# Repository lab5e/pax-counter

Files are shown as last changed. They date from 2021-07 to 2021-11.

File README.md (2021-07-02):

# PAX Counter

This device scans for visible bluetooth and wifi devices and then transmits the device count over NBIoT to a backend server.

IP67 version

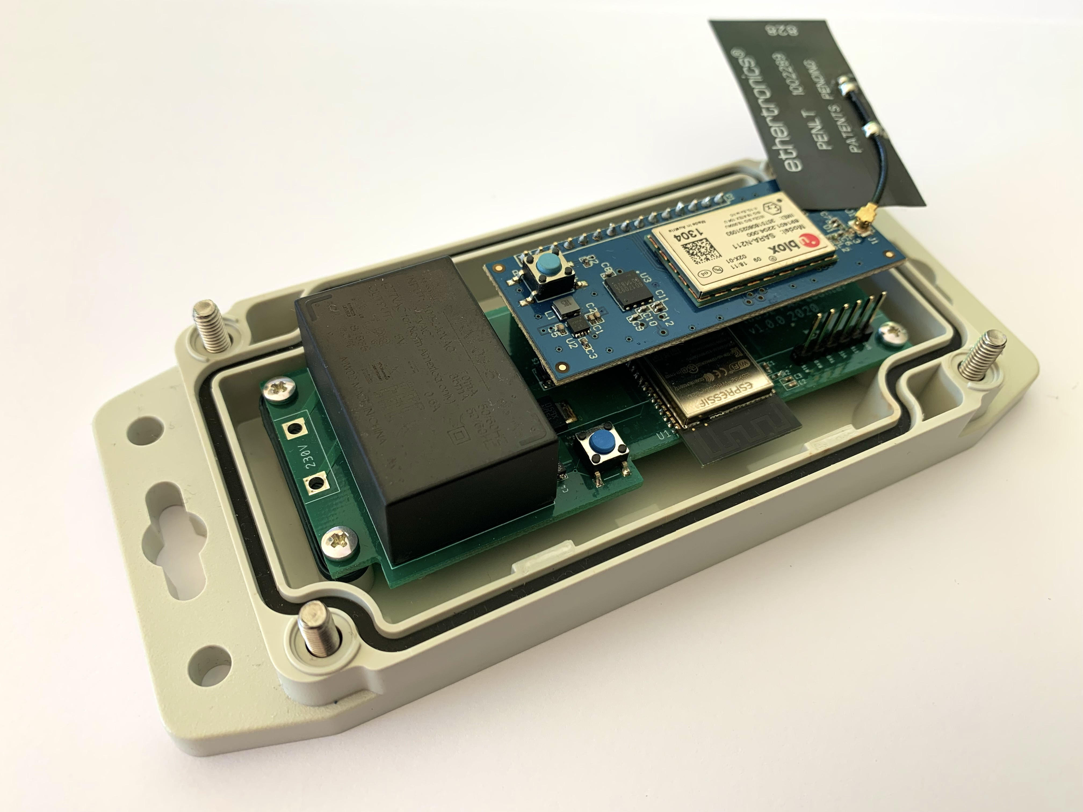
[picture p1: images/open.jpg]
open


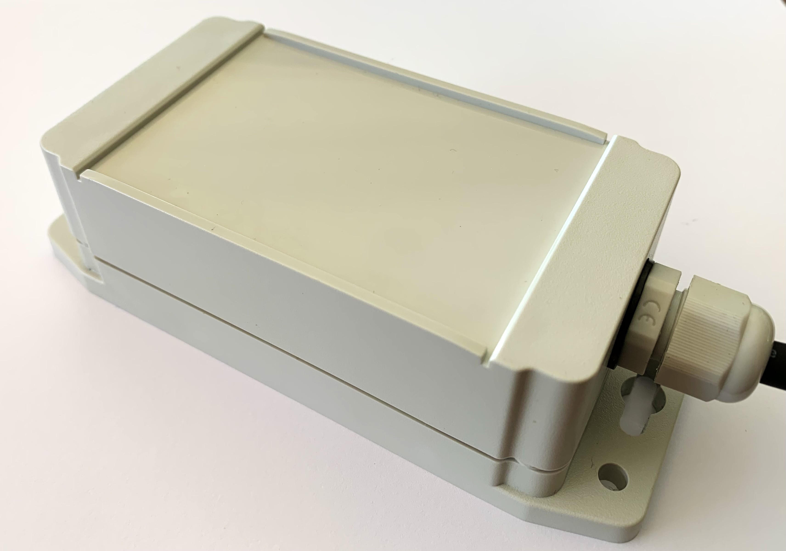
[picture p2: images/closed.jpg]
closed


Enclosure: [1555CF22GY](https://www.digikey.no/products/no?keywords=1555cf22) from Hammond Manufacturing

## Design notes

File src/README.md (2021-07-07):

# Note

Newer versions of BLEAdvertisedDevice.cpp, BLEAdvertisedDevice.h, BLEScan.h, BLEScan.cpp etc may be found here: [https://github.com/nkolban/esp32-snippets/tree/master/cpp_utils](https://github.com/nkolban/esp32-snippets/tree/master/cpp_utils).

(Consider switching to these if stuff get's weird)

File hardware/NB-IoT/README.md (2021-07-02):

# IP67 PAX Counter

## BoM

* C1	10uF 0402
* C2	10uF 0402
* C3	0.1uF CAP_0402
* C4	10uF Tantalum 1206
* C5	100uF Tantalum 1206
* J1	FTDI_CONNECTOR
* R1	10k	0402
* R2	10k		0402
* S1	SWITCH PTS645
* U1	ESP-WROOM-32D
* U2	15 pin female header (2.54)
* U3	IRM-03-5
* U4    LM1117	SOT-223
* [1555CF22GY](https://www.digikey.no/products/no?keywords=1555cf22) enclosure

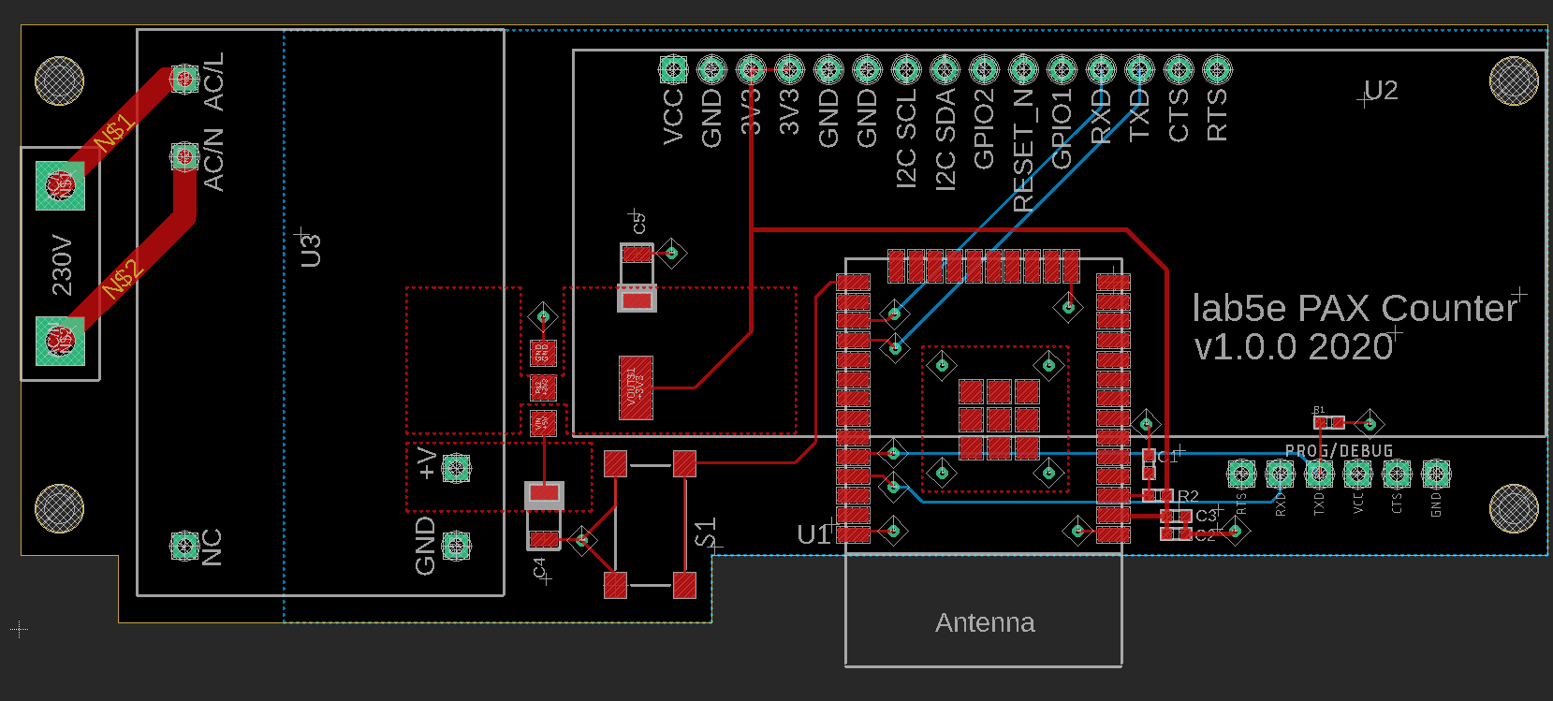
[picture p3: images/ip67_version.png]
Eagle board


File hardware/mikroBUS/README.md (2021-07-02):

# mikroBUS PAX Counter

(Work in progress)

## BoM
* ESP-WROOM-32D
* PTS645 SMT switch
* 2 x 0402 10k resistor
* 1 x 6 pin 2.54mm pin header
* 2 x 8 pin 2.54mm pin header

[mikroBUS specification](https://download.mikroe.com/documents/standards/mikrobus/mikrobus-standard-specification-v200.pdf)

Eagle board

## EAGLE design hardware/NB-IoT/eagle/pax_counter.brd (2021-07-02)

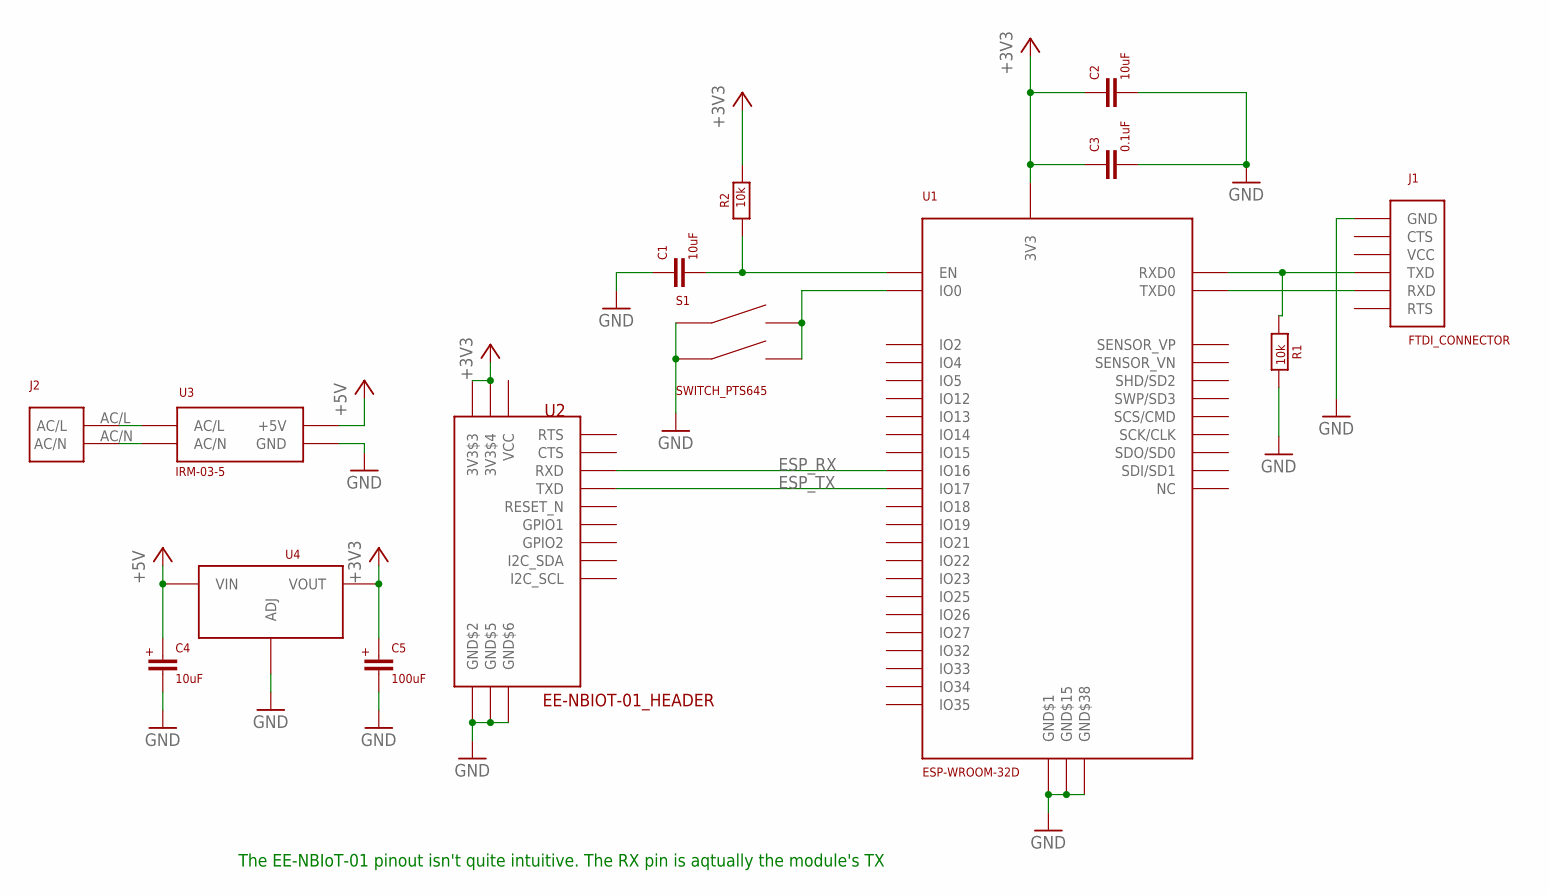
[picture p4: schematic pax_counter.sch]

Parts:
C1, C2: 10uF; CAP_0402
C3: 0.1uF; CAP_0402
C4: 10uF; TANTALUM_CAP_1206
C5: 100uF; TANTALUM_CAP_1206
J1: FTDI_CONNECTOR
J2: 240VAC_SOLDER_CONNECTOR
R1, R2: 10k; RES_0402
S1: SWITCH_PTS645; SWITCH_PTS645_EE_NBIOT_01
U1: ESP-WROOM-32D; ESP_WROOM_32D
U2: EE-NBIOT-01_HEADER
U3: IRM-03-5
U4: LM1117; SOT-223

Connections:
+3V3: C2.P$1 (1), C3.P$1 (1), C5.V+ (+), R2.P$2, U1.2 (3V3), U2.3V3$3, U2.3V3$4, U4.P$2 (VOUT), U4.VOUT$1 (VOUT)
+5V: C4.V+ (+), U3.+5V, U4.VIN
ESP_RX: U1.27 (IO16), U2.RXD
ESP_TX: U1.28 (IO17), U2.TXD
GND: C1.P$1 (1), C2.P$2 (2), C3.P$2 (2), C4.GND (-), C5.GND (-), J1.GND, R1.P$2, S1.A1, S1.A2, U1.1 (GND$1), U1.15 (GND$15), U1.38 (GND$38), U1.GND$39 (GND$38), U1.GND$40 (GND$38), U1.GND$41 (GND$38), U1.GND$42 (GND$38), U1.GND$43 (GND$38), U1.GND$44 (GND$38), U1.GND$45 (GND$38), U1.GND$46 (GND$38), U1.GND$47 (GND$38), U2.GND$2, U2.GND$5, U2.GND$6, U3.GND, U4.GND (ADJ)
unnamed: J2.AC/L, U3.AC/L
unnamed: J2.AC/N, U3.AC/N
unnamed: C1.P$2 (2), R2.P$1, U1.3 (EN)
unnamed: J1.TXD, R1.P$1, U1.34 (RXD0)
unnamed: J1.RXD, U1.35 (TXD0)
unnamed: S1.B1, S1.B2, U1.25 (IO0)

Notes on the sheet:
The EE-NBIoT-01 pinout isn't quite intuitive. The RX pin is aqtually the module's TX

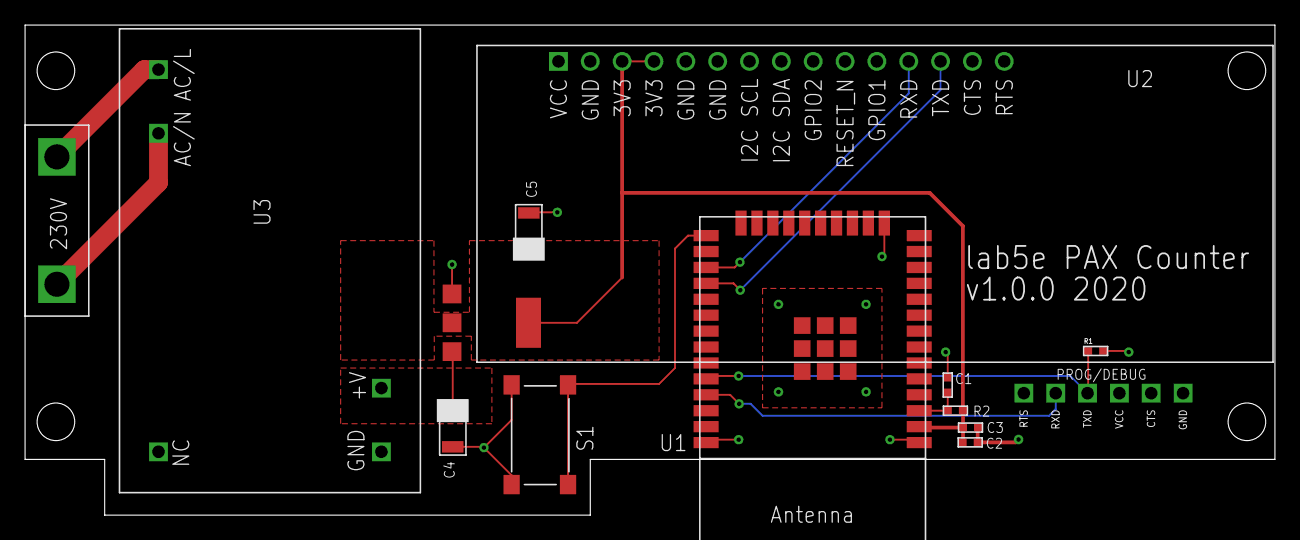
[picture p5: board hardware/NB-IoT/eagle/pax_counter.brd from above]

Board: 2 copper layers, 99.7 x 39.1 mm, 14 parts (0 on the bottom side), 11 nets.

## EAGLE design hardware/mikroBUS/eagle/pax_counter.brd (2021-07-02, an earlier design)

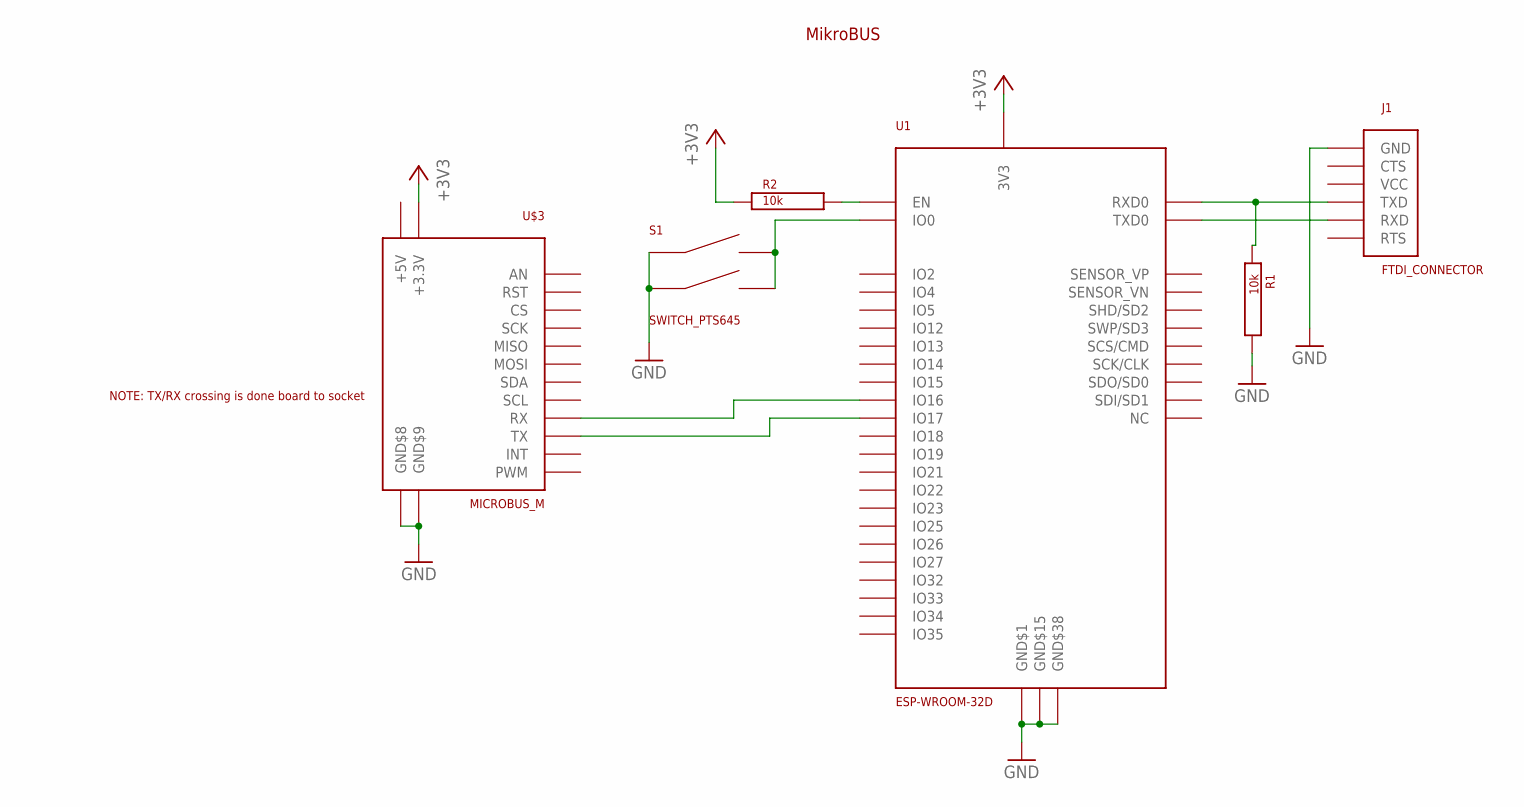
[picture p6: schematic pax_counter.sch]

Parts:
J1: FTDI_CONNECTOR
R1, R2: 10k; RES_0402
S1: SWITCH_PTS645; SWITCH_PTS645_EE_NBIOT_01
U1: ESP-WROOM-32D; ESP_WROOM_32D
U$1: MIKROBUS_LOGO
U$3: MICROBUS_M; MIKROBUS_M

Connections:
+3V3: R2.P$1, U1.2 (3V3), U$3.+3.3V
GND: J1.GND, R1.P$2, S1.A1, S1.A2, U1.1 (GND$1), U1.15 (GND$15), U1.38 (GND$38), U1.GND$39 (GND$38), U1.GND$40 (GND$38), U1.GND$41 (GND$38), U1.GND$42 (GND$38), U1.GND$43 (GND$38), U1.GND$44 (GND$38), U1.GND$45 (GND$38), U1.GND$46 (GND$38), U1.GND$47 (GND$38), U$3.GND$8, U$3.GND$9
unnamed: U1.27 (IO16), U$3.RX
unnamed: U1.28 (IO17), U$3.TX
unnamed: R2.P$2, U1.3 (EN)
unnamed: J1.TXD, R1.P$1, U1.34 (RXD0)
unnamed: J1.RXD, U1.35 (TXD0)
unnamed: S1.B1, S1.B2, U1.25 (IO0)

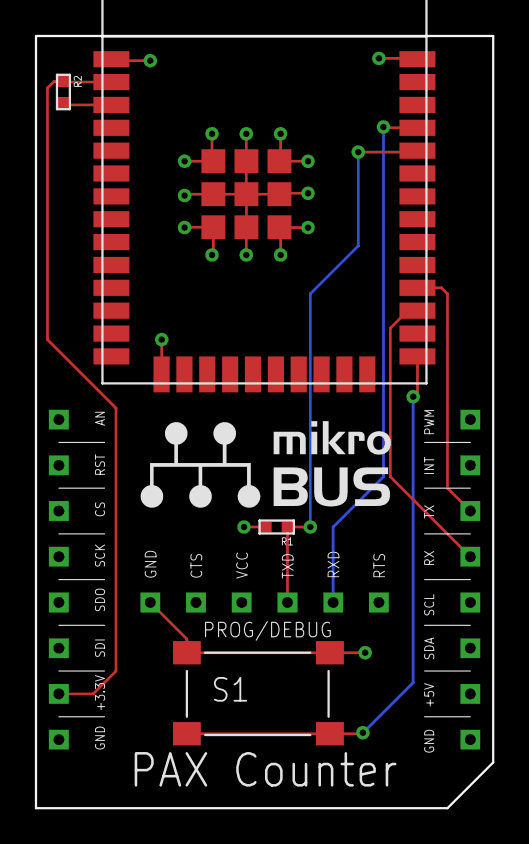
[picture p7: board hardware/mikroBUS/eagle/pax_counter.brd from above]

Board: 2 copper layers, 25.4 x 42.9 mm, 7 parts (0 on the bottom side), 8 nets.

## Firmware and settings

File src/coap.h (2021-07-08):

#ifndef _COAP_H_
#define _COAP_H_

#include <stdint.h>
#include <stddef.h>

// Default COAP parameters
#define DEFAULT_FOTA_COAP_REPORT_PATH   "u"
#define DEFAULT_FOTA_COAP_UPDATE_PATH   "fw"
#define DEFAULT_FOTA_COAP_PORT 5683


#define EINVAL   22

#define COAP_HEADER_VERSION(data)  ( (0xC0 & data[0])>>6    )
#define COAP_HEADER_TYPE(data)     ( (0x30 & data[0])>>4    )
#define COAP_HEADER_TKL(data)      ( (0x0F & data[0])>>0    )
#define COAP_HEADER_CLASS(data)    ( ((data[1]>>5)&0x07)    )
#define COAP_HEADER_CODE(data)     ( ((data[1]>>0)&0x1F)    )
#define COAP_HEADER_MID(data)      ( (data[2]<<8)|(data[3]) )

typedef struct
{
	char host[25];
	uint32_t port;
	char path[25];
	bool scheduled_update;
} simple_fota_response_t;

enum coap_method {
	COAP_METHOD_GET = 1,
	COAP_METHOD_POST = 2,
	COAP_METHOD_PUT = 3,
	COAP_METHOD_DELETE = 4,
};

#define COAP_REQUEST_MASK 0x07

struct coap_option {
	uint16_t delta;
#if defined(CONFIG_COAP_EXTENDED_OPTIONS_LEN)
	uint16_t len;
	uint8_t value[CONFIG_COAP_EXTENDED_OPTIONS_LEN_VALUE];
#else
	uint8_t len;
	uint8_t value[12];
#endif
};

enum coap_msgtype {
	/**
	 * Confirmable message.
	 *
	 * The packet is a request or response the destination end-point must
	 * acknowledge.
	 */
	COAP_TYPE_CON = 0,
	/**
	 * Non-confirmable message.
	 *
	 * The packet is a request or response that doesn't
	 * require acknowledgements.
	 */
	COAP_TYPE_NON_CON = 1,
	/**
	 * Acknowledge.
	 *
	 * Response to a confirmable message.
	 */
	COAP_TYPE_ACK = 2,
	/**
	 * Reset.
	 *
	 * Rejecting a packet for any reason is done by sending a message
	 * of this type.
	 */
	COAP_TYPE_RESET = 3
};

/**
 * @brief Set of CoAP packet options we are aware of.
 *
 * Users may add options other than these to their packets, provided
 * they know how to format them correctly. The only restriction is
 * that all options must be added to a packet in numeric order.
 *
 * Refer to RFC 7252, section 12.2 for more information.
 */
enum coap_option_num {
	COAP_OPTION_IF_MATCH = 1,
	COAP_OPTION_URI_HOST = 3,
	COAP_OPTION_ETAG = 4,
	COAP_OPTION_IF_NONE_MATCH = 5,
	COAP_OPTION_OBSERVE = 6,
	COAP_OPTION_URI_PORT = 7,
	COAP_OPTION_LOCATION_PATH = 8,
	COAP_OPTION_URI_PATH = 11,
	COAP_OPTION_CONTENT_FORMAT = 12,
	COAP_OPTION_MAX_AGE = 14,
	COAP_OPTION_URI_QUERY = 15,
	COAP_OPTION_ACCEPT = 17,
	COAP_OPTION_LOCATION_QUERY = 20,
	COAP_OPTION_BLOCK2 = 23,
	COAP_OPTION_BLOCK1 = 27,
	COAP_OPTION_SIZE2 = 28,
	COAP_OPTION_PROXY_URI = 35,
	COAP_OPTION_PROXY_SCHEME = 39,
	COAP_OPTION_SIZE1 = 60,
};

struct coap_packet 
{
	uint8_t *data;      // User allocated buffer 
	uint16_t offset;    // CoAP lib maintains offset while adding data 
	uint16_t max_len;   // Max CoAP packet data length 
	uint8_t hdr_len;    // CoAP header length 
	uint16_t opt_len;   // Total options length (delta + len + value) 
	uint16_t delta;     // Used for delta calculation in CoAP packet 
};

enum coap_block_size {
	COAP_BLOCK_16,
	COAP_BLOCK_32,
	COAP_BLOCK_64,
	COAP_BLOCK_128,
	COAP_BLOCK_256,
	COAP_BLOCK_512,
	COAP_BLOCK_1024,
};

// Represents the current state of a block-wise transaction.
struct coap_block_context {
	size_t total_size;
	size_t current;
	enum coap_block_size block_size;
};

#define coap_make_response_code(class, det) ((class << 5) | (det))


//  Set of response codes available for a response packet.
// 
//  To be used when creating a response.
// 
enum coap_response_code {
	COAP_RESPONSE_CODE_OK = coap_make_response_code(2, 0),
	COAP_RESPONSE_CODE_CREATED = coap_make_response_code(2, 1),
	COAP_RESPONSE_CODE_DELETED = coap_make_response_code(2, 2),
	COAP_RESPONSE_CODE_VALID = coap_make_response_code(2, 3),
	COAP_RESPONSE_CODE_CHANGED = coap_make_response_code(2, 4),
	COAP_RESPONSE_CODE_CONTENT = coap_make_response_code(2, 5),
	COAP_RESPONSE_CODE_CONTINUE = coap_make_response_code(2, 31),
	COAP_RESPONSE_CODE_BAD_REQUEST = coap_make_response_code(4, 0),
	COAP_RESPONSE_CODE_UNAUTHORIZED = coap_make_response_code(4, 1),
	COAP_RESPONSE_CODE_BAD_OPTION = coap_make_response_code(4, 2),
	COAP_RESPONSE_CODE_FORBIDDEN = coap_make_response_code(4, 3),
	COAP_RESPONSE_CODE_NOT_FOUND = coap_make_response_code(4, 4),
	COAP_RESPONSE_CODE_NOT_ALLOWED = coap_make_response_code(4, 5),
	COAP_RESPONSE_CODE_NOT_ACCEPTABLE = coap_make_response_code(4, 6),
	COAP_RESPONSE_CODE_INCOMPLETE = coap_make_response_code(4, 8),
	COAP_RESPONSE_CODE_PRECONDITION_FAILED = coap_make_response_code(4, 12),
	COAP_RESPONSE_CODE_REQUEST_TOO_LARGE = coap_make_response_code(4, 13),
	COAP_RESPONSE_CODE_UNSUPPORTED_CONTENT_FORMAT =
						coap_make_response_code(4, 15),
	COAP_RESPONSE_CODE_INTERNAL_ERROR = coap_make_response_code(5, 0),
	COAP_RESPONSE_CODE_NOT_IMPLEMENTED = coap_make_response_code(5, 1),
	COAP_RESPONSE_CODE_BAD_GATEWAY = coap_make_response_code(5, 2),
	COAP_RESPONSE_CODE_SERVICE_UNAVAILABLE = coap_make_response_code(5, 3),
	COAP_RESPONSE_CODE_GATEWAY_TIMEOUT = coap_make_response_code(5, 4),
	COAP_RESPONSE_CODE_PROXYING_NOT_SUPPORTED =
						coap_make_response_code(5, 5)
};

#define COAP_CODE_EMPTY (0)
#define COAP_TOKEN_MAX_LEN 8UL

#define ceiling_fraction(numerator, divider) \
	(((numerator) + ((divider) - 1)) / (divider))

#define ARRAY_SIZE(array) (sizeof(array) / sizeof((array)[0]))

int sys_csrand_get	(void * dst, size_t len);

int coap_packet_init(struct coap_packet *cpkt, uint8_t *data, uint16_t max_len,
		     uint8_t ver, uint8_t type, uint8_t token_len,
		     const uint8_t *token, uint8_t code, uint16_t id);

int fota_report_version(simple_fota_response_t *resp);



void test_coap();

#endif // _COAP_H_

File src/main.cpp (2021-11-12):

#include <Arduino.h>

#include "TelenorNBIot.h"
#include "wifi_scan.h"
#include "ble_scan.h"
#include "mac_pool.h"
#include <esp_task_wdt.h> 



MACAddressPool pool(300000); // Age limit: 5 minutes

#define TRANSMIT_DELAY_MS 1000 * 60 * 2 // Transmit every 2 minutes
#define BOOT_DELAY_MS 1000 * 60 * 120  // Reboot every second hour

extern "C" 
{
  uint8_t temprature_sens_read();
}

// void(* resetFunc) (void) = 0;

#define WDT_TIMEOUT 3 * 60 // 3 minute watchdog

void setup() 
{
  Serial.begin(115200);
  delay(1000);
  Serial.printf("Enabling watchdog timer. Timeout: %d\n", WDT_TIMEOUT);
  esp_task_wdt_init(WDT_TIMEOUT, true); //enable panic so ESP32 restarts
  esp_task_wdt_add(NULL); //add current thread to WDT watch

  wifi_scanner_setup();
  ble_scanner_setup();
  nbiot_setup();
 }

uint32_t seconds_uptime = 0;
uint sequence_number = 0;
void loop() 
{
  unsigned long boot_time_start, boot_time_end, transmit_time_start, transmit_time_end;

  boot_time_start = millis();
  while (true)
  {
    transmit_time_start = millis();
    while (true)
    {
      wifi_scan();
      ble_scanner_setup();
      ble_scan();
      ble_scanner_teardown();
      nbiot_status();
      esp_task_wdt_reset();
      pool.Log();
      transmit_time_end  = millis();
      boot_time_end = millis();
      float core_temperature = (temprature_sens_read() - 32) / 1.8;
      Serial.print("Core temperature:");
      Serial.println(core_temperature);
      if (transmit_time_end-transmit_time_start > TRANSMIT_DELAY_MS)
      {
        Serial.println("Transmitting...");
        sequence_number++;
        int uptime_s = boot_time_end / 1000;
        Serial.print("Uptime:");
        Serial.println(uptime_s);
        Serial.print("Sequence number:");
        Serial.println(sequence_number);
        nbiot_transmit_message(pool.get_count(BT), pool.get_count(WIFI), core_temperature, sequence_number, uptime_s);
        pool.Purge();
        Serial.println("Log purged.");
        break;
      }
    }
    if (boot_time_end-boot_time_start > BOOT_DELAY_MS)
    {
      sleep(2*WDT_TIMEOUT);
    }
  }
}

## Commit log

2021-07-02 Updated with latest hardware design
    * Board definition
    * Schematics
    * Bill of materials
    * New images
    [pax_counter.brd, pax_counter.sch]
2021-07-02 Moved eagle files for IP67 version
    [pax_counter.brd, pax_counter.sch]
2021-07-02 Added readme for IP67 / NB-IoT version
    * Board image
    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
2021-07-05 Fixed APN
    * IP address debug output
    * Removed debug output
    [TelenorNBIoT.cpp, main.cpp]
2021-07-06 Added time triggers for TX and reboot
    [main.cpp]
2021-07-06 Added sensing of core temperature
    * extended message with core temperature reading
2021-07-07 Updated partition table added BLE teardown func
    * Added mew README with links to newer versions of BLE framework
    classes
    * Added flag in platformio.ini for enabling HAL level logging
    * Added flag in platformio.ini for using custom partition table
    * Added teardown function for BLE
    * Added rudimentary logging in advertised callback (will use this in
    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
2021-07-08 Work in progress (coap + partition magic)
    * added coap functions
    * extended partition table with app1 region
    * changed app partition size in order to fit everything within 4Mb
    [pax_partition_table.csv]
2021-11-09 Updated partition table
    * removed excessive logging in BLE scanner
    [pax_partition_table.csv]
2021-11-12 Partition table ok
    * 3 test sensors prepared
